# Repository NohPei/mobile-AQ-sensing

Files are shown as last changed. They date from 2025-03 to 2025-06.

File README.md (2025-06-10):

**NOTE:** *this repository and README file are still actively under development* 
---

*last updated: 6/9/2025*

# Mobile AQ Sensing Unit Overview

- **Raspberry Pi 4B** (Raspberry Pi OS Bookworm)
- **DS3231 RTC** (real-time clock module)
- **MQ Gas Sensors**:
  - MQ-3 (Alcohol)
  - MQ-4 (Methane)
  - MQ-8 (Hydrogen)
  - All read via **ADS1115 16-bit ADC**
- **Adafruit Breakout board Plantower PMSA003I** (Particulate Matter Sensor, PM1.0 / PM2.5 / PM10)
- **GY-BNO08X** (9 DoF IMU — accelerometer, gyro, magnetometer)
- **Adafruit SCD41** (True/NDIR CO₂, Temperature, Humidity)
- **Adafruit ENS160 MOX Gas Sensor** (TVOC, AQI, eCO₂)
- **DFRobot SEN0571** (Qualitative Odor Sensor)
- **GT-U7 GPS & GNSS Antenna Amplifier**

- [3D printed enclosure](https://github.com/NohPei/mobile-AQ-documentation/blob/main/v2-enclosure.stl)

**NOTE:** why both ENS160 and SCD41? We could use only SCD41 to measure *true* CO₂ (which isn't affected by VOCs like the ENS160), but we wanted something to measure TVOC/VOCs
- while ENS160 is currently included, we are actively searching to replace it with an alternative sensor for VOCs only

### TVOC vs. VOC
- VOCs (Volatile Organic Compounds) = individual or specific groups of volatile organic compounds.
- TVOC (Total Volatile Organic Compounds) = represents the total concentration of all volatile organic compounds in the air.

# How are the different sensors interfaced?
- I2C: RTC, MQs (x3), IMU, ENS160, SCD41, PM
- UART: GPS

# Sensors + Data Structure 
Overview and in-depth resources for the sensors, type of data they capture, and output format of the CSV.

Each row in the CSV file contains a timestamped sensor reading from the mobile air quality sensing unit. The columns are listed below:

| Column Name | Description | Units |
|---|---|---|
| `Timestamp (ms)` | System timestamp when data was logged | milliseconds |
| `GPS Timestamp(UTC)`| UTC timestamp from GPS module | ISO 8601 or seconds |
| `Latitude` | Latitude position from GPS | degrees |
| `Longitude` | Longitude position from GPS | degrees |
| `MQ-3 Voltage` | Raw analog voltage from MQ-3 sensor | volts |
| `MQ-4 Voltage` | Raw analog voltage from MQ-4 sensor | volts |
| `MQ-8 Voltage` | Raw analog voltage from MQ-8 sensor | volts |
| `MQ-3 R_s` | Sensor resistance for MQ-3 | ohms (Ω) |
| `MQ-4 R_s` | Sensor resistance for MQ-4 | ohms (Ω) |
| `MQ-8 R_s` | Sensor resistance for MQ-8 | ohms (Ω) |
| `SCD41 CO₂` | CO₂ concentration | ppm |
| `SCD41 Temperature` | Ambient temperature | °C |
| `SCD41 Humidity` | Relative humidity | % |
| `PM1.0` | Particulate matter 1.0 µm concentration | µg/m³ |
| `PM2.5` | Particulate matter 2.5 µm concentration | µg/m³ |
| `PM10` | Particulate matter 10 µm concentration | µg/m³ |
| `Accel X` | X-axis acceleration | m/s² |
| `Accel Y` | Y-axis acceleration | m/s² |
| `Accel Z` | Z-axis acceleration | m/s² |
| `Gyro X` | X-axis angular velocity | °/s |
| `Gyro Y` | Y-axis angular velocity | °/s |
| `Gyro Z` | Z-axis angular velocity | °/s |
| `Mag X` | X-axis magnetic field | µT |
| `Mag Y` | Y-axis magnetic field | µT |
| `Mag Z` | Z-axis magnetic field | µT |

### Real-Time Clock (ds3231) -> Timestamp (ms)
- ex) 2025-05-07 00:34:16.522

### GPS (GT-U7 + GNSS antenna amplifier) -> GPS Timestamp (UTC), Latitude,Longitude
- ex) 2025-05-07 04:34:16,42.29262116666666,-83.71489916666667

### Gas Sensors (MQ Series) -> Voltage
[resource 1](https://www.theengineeringprojects.com/2024/04/mq-gas-sensor-series.html)
[resource 2](https://robocraze.com/blogs/post/mq-series-gas-sensor)
[resource 3](https://iotbyhvm.ooo/mq-gas-sensors-gas-sensors/)

MQ-3 = H2, LPG, CH4, CO, Alcohol, Smoke or Propane
- [MQ-3 datasheet](https://cdn.sparkfun.com/assets/6/a/1/7/b/MQ-3.pdf)
MQ-4 = Methane, CNG
MQ-8 = Hydrogen Sulfide 
- outputs are voltages, representing raw output from sensor 
    - reflects concentration of gas it is sensing 

- ex) 0.3605,0.165,0.34450000000000003
**note**: tells us the concentration of a gas in part per million (ppm) according to the resistance ratio of the sensor (RS/R0). MQ senors have a built-in variable resistor that changes its value according to the concentration of gas. If the concentration is High, the resistance decreases,  if the concentration is low, the resistance increases

MQ-3 R_s,MQ-4 R_s,MQ-8 R_s
ex) 128696.25520110958,293030.303030303,135137.88098693758,

(ENS160 is optional...)
ENS160 TVOC,ENS160 eCO₂,ENS160 AQI
datasheet: https://cdn-learn.adafruit.com/assets/assets/000/115/331/original/SC_001224_DS_1_ENS160_Datasheet_Rev_0_95-2258311.pdf 
TVOC values: 0 - 65,000
eCO₂ values: 400 - 65,000 
AQI values: 1-5
- ex) 0,400,1

SCD41 CO₂,SCD41 Temperature,SCD41 Humidity,
ex) 590,24.380483710994127,29.660486762798506

DFROBOT SEN0571 Odor Sensor (*qualitative* sensor...)
[resource](https://docs.cirkitdesigner.com/component/8f45805b-c744-4d19-9426-4d6299082ad4/fermion-mems-odor-smell-gas-detection-sensor) <- although the wiring instructions are incorrect, that resource has good notes

PM1.0,PM2.5,PM10
ex) 1,1,3

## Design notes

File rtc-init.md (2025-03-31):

### DS3231 RTC Setup on Raspberry Pi OS (Bookworm)

To get the DS3231 RTC working reliably on Raspberry Pi OS (Bookworm), follow these steps:

1. enable i2c using `sudo raspi-config`, and verify the RTC is detected at address `0x68` using `i2cdetect -y 1`.
2. In `/boot/firmware/config.txt`, add the following line all the way at the bottomt to enable the overlay:

```ini
dtoverlay=i2c-rtc,ds3231
```
3. Add the RTC driver to `/etc/modules`: (underscore!)
```ini
rtc_ds1307
```
4. Add the driver to `/etc/initramfs-tools/modules`: (hyphen!)
```ini
rtc-ds1307
```
- then update initramfs tools:
```bash
sudo update-initramfs -u
```

5. Create fallback script at `/usr/local/bin/fallback_rtc_init.sh`:
```bash
#!/bin/bash

LOG_TAG="FALLBACK_RTC"
I2C_BUS=1
RTC_ADDRESS=0x68

logger -t "$LOG_TAG" "Starting RTC fallback init..."

# Load RTC driver
modprobe rtc_ds1307
logger -t "$LOG_TAG" "Loaded rtc_ds1307 driver."

# If /dev/rtc0 doesn't exist, try to register the device
if [ ! -e /dev/rtc0 ]; then
    logger -t "$LOG_TAG" "/dev/rtc0 not found. Attempting manual registration..."
    echo "ds3231 $RTC_ADDRESS" > /sys/class/i2c-adapter/i2c-${I2C_BUS}/new_device 2>/dev/null
    sleep 1
fi

# If RTC is now present
if [ -e /dev/rtc0 ]; then
    logger -t "$LOG_TAG" "RTC registered successfully at /dev/rtc0."
    sleep 1

    # Check system time before setting it from RTC
    CURRENT_YEAR=$(date +%Y)
    if [ "$CURRENT_YEAR" -lt 2022 ]; then
        if hwclock -s; then
            logger -t "$LOG_TAG" "System time set from RTC: $(hwclock -r)"
        else
            logger -t "$LOG_TAG" "ERROR: hwclock failed to read from RTC after registration."
        fi
    else
        logger -t "$LOG_TAG" "System time already appears valid. Skipping hwclock -s."
    fi
else
    logger -t "$LOG_TAG" "ERROR: /dev/rtc0 still not available. RTC registration failed or device not present."
fi
```
- make it executable: `sudo chmod +x /usr/local/bin/fallback_rtc_init.sh`

6. Make the systemd serivce (load module, manually register if missing, set system clock) at `/etc/systemd/system/fallback-rtc.service`:
```ini
[Unit]
Description=Manual Fallback RTC Init
After=multi-user.target
ConditionPathExists=/dev/i2c-1

[Service]
Type=oneshot
ExecStart=/usr/local/bin/fallback_rtc_init.sh
RemainAfterExit=yes

[Install]
WantedBy=multi-user.target
```
- reload & enable that:
```bash
sudo systemctl daemon-reload
sudo systemctl enable fallback-rtc.service
```

7. (optional/overkill but good for system longevity and consistency) sync RTC if NTP sync happens (pi connects to network) at `/usr/local/bin/rtc_writeback.sh`:
```bash
#!/bin/bash

LOG_TAG="RTC_WRITEBACK"

logger -t "$LOG_TAG" "Waiting for NTP synchronization..."

MAX_TRIES=60
for i in $(seq 1 $MAX_TRIES); do
    SYNCED=$(timedatectl show -p NTPSynchronized --value)
    if [ "$SYNCED" = "yes" ]; then
        logger -t "$LOG_TAG" "System clock synchronized, writing to RTC..."
        hwclock -w && logger -t "$LOG_TAG" "RTC updated from system time."
        exit 0
    fi
    sleep 2
done

logger -t "$LOG_TAG" "ERROR: NTP sync not achieved within timeout."
exit 1
```
- make it executable: `sudo chmod +x /usr/local/bin/rtc_writeback.sh`

8. Create the systemd service for it at `/etc/systemd/system/rtc-writeback.service`:
```ini
[Unit]
Description=Write system time to RTC after NTP sync
After=network-online.target systemd-timesyncd.service
Requires=systemd-timesyncd.service

[Service]
Type=oneshot
ExecStart=/usr/local/bin/rtc_writeback.sh
TimeoutStartSec=90

[Install]
WantedBy=multi-user.target
```
- reload & enable that:
```bash
sudo systemctl daemon-reload
sudo systemctl enable fallback-rtc.service
```

### Summary:   
1. this will make RTC work on every boot with/without connectivity and set the system time to correctly use the hardware clock. 
2. bonus: will resync with NTP when Wi-Fi connectivity happens so RTC is updated from system time.

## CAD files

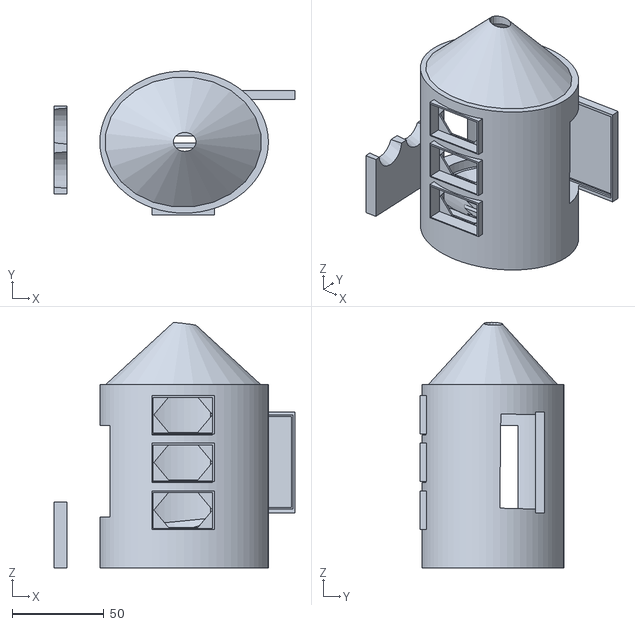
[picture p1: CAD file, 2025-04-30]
v2-enclosure.stl
131.5 x 78.5 x 134.0

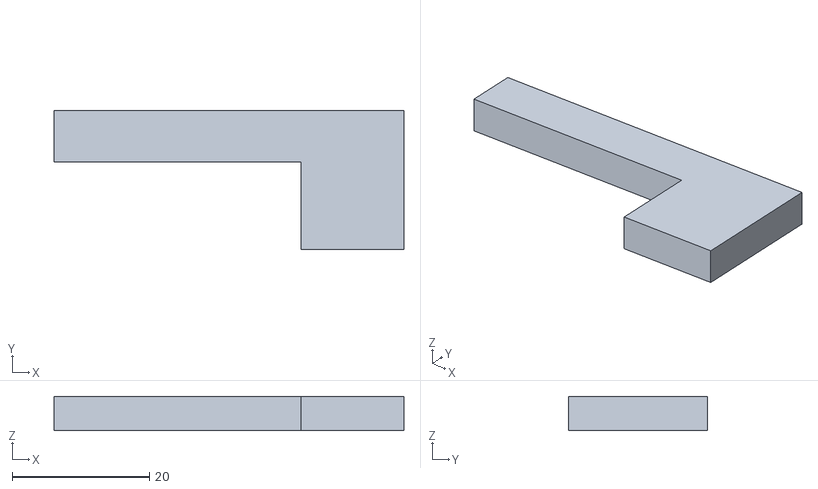
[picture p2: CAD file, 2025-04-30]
PM_sensor_plug.stl
51.0 x 20.2 x 5.00

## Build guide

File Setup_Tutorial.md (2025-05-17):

# Mobile Gas Sensing Module Setup Tutorial

## Table of Contents

1. [Introduction](#introduction)
2. [Hardware Requirements](#hardware-requirements)
3. [Assembly Instructions](#assembly-instructions)
4. [Software Setup](#software-setup)
   - [Operating System Installation](#operating-system-installation)
   - [Required Libraries](#required-libraries)
   - [Sensor Configuration](#sensor-configuration)
5. [RTC Configuration](#rtc-configuration)
   - [DS3231 Setup](#ds3231-setup)
   - [Time Synchronization](#time-synchronization)
6. [Data Collection](#data-collection)
7. [Troubleshooting](#troubleshooting)
8. [Maintenance](#maintenance)
9. [References](#references)

## Introduction

This guide provides step-by-step instructions for building and configuring a mobile gas sensing module from scratch. Follow each section in order for a complete setup.

## Software Requirement

#### Operating System Installation

Download it through https://www.raspberrypi.com/software/

In this repo, Raspberry Pi 5, 64 bit enhanced version is installed

#### Required Libraries (in python venv)
To make sure you can access the sysled as indication. You can run following command to create new rule and change the permission of sysled:

```
sudo nano /etc/udev/rules.d/99-led-permissions.rules
```

Type following command in the new rules:
```
SUBSYSTEM=="leds", KERNEL=="ACT", MODE="0666"
```

Reload rules:
```
sudo udevadm control --reload-rules
sudo udevadm trigger
```

If none of the above things work, manually modify the permission with 
```
sudo chmod 666 /sys/class/leds/ACT/brightness
```

1. ADS1115 => pip install adafruit-circuitpython-ads1x15
2. lgpio (not defaulty installed for pi5, higher performance) => pip install lgpio
3.

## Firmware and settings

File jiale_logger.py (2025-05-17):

import board # board pinout abstract
import busio # board bus abstract
import adafruit_ads1x15.ads1115 as ADS # Four channel ADC
from adafruit_ads1x15.analog_in import AnalogIn # Analog read function
import adafruit_scd4x # CO2 sensor

import os
import time
from datetime import datetime,timezone
import pytz
import csv
import argparse

import matplotlib.pyplot as plt
from matplotlib.animation import FuncAnimation
from collections import deque
import threading
import queue

import utils
from utils import config
print("utils imported")

class DataCollector(threading.Thread):
    def __init__(self, data_queue):
        super().__init__()
        self.data_queue = data_queue
        self.running = True
        self.daemon = True  # Thread will exit when main program exits

    def run(self):
        # Initialize sensors
        i2c = busio.I2C(board.SCL, board.SDA, frequency=config.I2C_FREQ) 
        ads = ADS.ADS1115(i2c, address=config.I2C_ADDRESS)
        scd41 = adafruit_scd4x.SCD4X(i2c)
        mq_sensors = {
            "MQ-3 (Alcohol)": AnalogIn(ads, ADS.P0),
            "MQ-4 (Methane)": AnalogIn(ads, ADS.P1),
            "MQ-8 (Hydrogen)": AnalogIn(ads, ADS.P3)
        }
        scd41.start_periodic_measurement()
        # Add the warm-up function call here
        print("Starting sensor warm-up...")
        utils.warm_up(5)  # Pass the number of seconds to warm up
        print("Warm-up complete, beginning data collection")
        csv_filename = f"sensor_log.csv"
        with open(csv_filename, mode='w', newline='') as file:
            writer = csv.writer(file)
            writer.writerow(config.SENSOR_HEADERS)
            print("Logging data to {}. Ctrl+C to stop.".format(csv_filename))
            
            while self.running:
                timestamp = datetime.now()
                mq_readings = [mq_sensor.voltage for mq_sensor in mq_sensors.values()]
                if scd41.data_ready:
                    scd41_readings = [scd41.CO2, scd41.temperature, scd41.relative_humidity]
                else:
                    scd41_readings = [-1, -1, -1]
                # Write to CSV
                writer.writerow([timestamp.strftime("%Y-%m-%d %H:%M:%S.%f")[:-3],
                                *mq_readings, 
                                *scd41_readings])
                file.flush()
                
                # Send data to plotting thread
                if self.data_queue is not None:
                    self.data_queue.put((timestamp, 
                                         *mq_readings, 
                                         *scd41_readings))
                time.sleep(0.1)  # Adjust sampling rate as needed

    def stop(self):
        self.running = False

def main():
    parser = argparse.ArgumentParser(description='Gas sensor data logger with optional plotting')
    parser.add_argument('--plot', action='store_true', help='Enable plotting')
    args = parser.parse_args()
    plot_enabled = args.plot
    # Set up the LED
    utils.set_led(0)

    if plot_enabled:
        # Create figure and axes
        fig, ax = plt.subplots(4, 1, figsize=(10, 8))
        max_points = 100
        
        # Create deques for data
        times = deque(maxlen=max_points)
        mq3_data = deque(maxlen=max_points)
        mq4_data = deque(maxlen=max_points)
        mq8_data = deque(maxlen=max_points)
        co2_data = deque(maxlen=max_points)

        # Initialize plots
        lines = []
        labels = ['MQ-3 (Alcohol)', 
                  'MQ-4 (Methane)', 
                  'MQ-8 (Hydrogen)',
                  'CO2 (ppm)']
        for i, axis in enumerate(ax):
            line, = axis.plot([], [], 'r-', label=labels[i])
            lines.append(line)
            if i == 3:
                axis.set_ylabel('CO2 (ppm)')
                axis.set_ylim(400, 5000)
            else:
                axis.set_ylabel('Voltage (V)')
            axis.set_xlabel('Time (s)')
            axis.grid(True)
            axis.legend()


        start_time = None
        data_queue = queue.Queue()
    else:
        data_queue = None
        print("Plotting disabled")
    
    # Create and start data collector thread
    collector = DataCollector(data_queue)
    collector.start()

    if plot_enabled:
        def update_plot(frame):
            nonlocal start_time
            
            # Get all available data from queue
            while not data_queue.empty():
                timestamp, mq3, mq4, mq8, co2, temp, hum = data_queue.get()
                if start_time is None:
                    start_time = timestamp

                elapsed = (timestamp - start_time).total_seconds()

                times.append(elapsed)
                mq3_data.append(mq3)
                mq4_data.append(mq4)
                mq8_data.append(mq8)
                if co2 is not None:
                    co2_data.append(co2)
                elif len(co2_data) > 0:
                    co2_data.append(co2_data[-1])
                else:
                    co2_data.append(0)

            # Update each line
            data_sets = [mq3_data, mq4_data, mq8_data, co2_data]
            for i, (line, data) in enumerate(zip(lines, data_sets)):
                line.set_data(list(times), list(data))
                axis = line.axes
                axis.relim()
                axis.autoscale_view()

            return lines

        # Start animation in main thread
        ani = FuncAnimation(fig, update_plot, interval=10, blit=True, save_count=max_points)

        try:
            plt.show()
        except KeyboardInterrupt:
            pass
    else:
        try:
            print("Press Ctrl+C to stop")
            while True:
                time.sleep(1)
        except KeyboardInterrupt:
            pass
    collector.stop()
    collector.join()
    if plot_enabled:
        plt.close()
    print("Logger stopped")

if __name__ == "__main__":
    main()

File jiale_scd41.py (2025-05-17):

import time
import board
import adafruit_scd4x
from utils import config
import busio

i2c = busio.I2C(board.SCL, board.SDA, frequency=config.I2C_FREQ) 
scd4x = adafruit_scd4x.SCD4X(i2c)
scd4x.reinit()

print("Starting measurements...")
scd4x.start_periodic_measurement()
initial_time = time.time()
while True:
    if scd4x.data_ready:
        scd4x_readings = [scd4x.CO2, scd4x.temperature, scd4x.relative_humidity]
        print("Elapsed time since last measurement: ", time.time() - initial_time)
        print(f"CO2: {scd4x_readings[0]}ppm, Temperature: {scd4x_readings[1]}C, Humidity: {scd4x_readings[2]}%")
        initial_time = time.time()
        time.sleep(5)

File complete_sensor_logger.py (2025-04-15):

import time
import board
import busio
import serial
import csv
import threading
import glob
from datetime import datetime
import pynmea2
import adafruit_scd4x
import adafruit_ens160
import adafruit_ads1x15.ads1115 as ADS
from adafruit_ads1x15.analog_in import AnalogIn
import adafruit_bno08x
from adafruit_bno08x.i2c import BNO08X_I2C
from adafruit_ens160 import NORMAL_OP, START_UP, WARM_UP, INVALID_OUT, MODE_STANDARD
from adafruit_pm25.i2c import PM25_I2C

# using ACT led to verify we have started logging data
led_path="/sys/class/leds/ACT/brightness"

def set_led(state):
  with open(led_path, "w") as led:
    led.write("1" if state else "0")
set_led(0)

# Initialize I2C - added frequency for PM sensor...
reset_pin = None
i2c = busio.I2C(board.SCL, board.SDA, frequency=100000)

# Initialize ADS1115 (MQ Gas Sensors)
ads = ADS.ADS1115(i2c)
mq_sensors = {
    "MQ-3 (Alcohol)": AnalogIn(ads, ADS.P0),
    "MQ-4 (Methane)": AnalogIn(ads, ADS.P1),
    "MQ-8 (Hydrogen)": AnalogIn(ads, ADS.P3)
}

# Initialize IMU (GY-BNO08X)
imu = BNO08X_I2C(i2c, address=0x4B)
imu.enable_feature(adafruit_bno08x.BNO_REPORT_ACCELEROMETER)
imu.enable_feature(adafruit_bno08x.BNO_REPORT_GYROSCOPE)
imu.enable_feature(adafruit_bno08x.BNO_REPORT_MAGNETOMETER)

# Initialize Serial Interfaces
gps_uart = serial.Serial("/dev/ttyAMA0", baudrate=9600, timeout=0.1)

# Initialize Sensors
ens160 = adafruit_ens160.ENS160(i2c)
ens160.mode = MODE_STANDARD
scd41 = adafruit_scd4x.SCD4X(i2c)
scd41.start_periodic_measurement()
pm25 = PM25_I2C(i2c, reset_pin)

print("ENS160 firmware:", ens160.firmware_version)
print("ENS160 mode:", ens160.mode)

# Store latest GPS coordinates and time
gps_lock = threading.Lock()
latest_lat, latest_lon, latest_gps_time = None, None, None
last_gps_fix_timestamp = None

# **Threaded GPS Reading**
def read_gps_continuous():
    global latest_lat, latest_lon, latest_gps_time, last_gps_fix_timestamp
    while True:
        try:
            line = gps_uart.readline().decode('utf-8', errors='ignore').strip()
            if line.startswith("$GPRMC"):
                msg = pynmea2.parse(line)
                if msg.status == 'A':
                    gps_datetime = datetime.combine(msg.datestamp, msg.timestamp)
                    with gps_lock:
                        latest_gps_time = gps_datetime
                        last_gps_fix_timestamp = time.time()
            elif line.startswith("$GPGGA"):
                msg = pynmea2.parse(line)
                if hasattr(msg, 'gps_qual') and msg.gps_qual > 0:
                    with gps_lock:
                        latest_lat, latest_lon = msg.latitude, msg.longitude
                        last_gps_fix_timestamp = time.time()
        except Exception as e:
            print(f"GPS Error: {e}")
        time.sleep(0.05)

# Start GPS Thread
gps_thread = threading.Thread(target=read_gps_continuous, daemon=True)
gps_thread.start()

# **Warm-Up Period (1 Minute)**
warmup_time = 1 * 60
print(f"Starting warm-up period ({warmup_time // 60} minutes)...")
start_time = time.time()
while time.time() - start_time < warmup_time:
    remaining_time = warmup_time - (time.time() - start_time)
    print(f"Warm-up time remaining: {int(remaining_time // 60)}m {int(remaining_time % 60)}s", end="\r")
    set_led(1)
    time.sleep(1)
    set_led(0)
    time.sleep(1)
print("\nWarm-up complete. Starting data collection...")

set_led(1)

# **Create and Open CSV File for Logging**
first_timestamp = datetime.now().strftime("%Y-%m-%d_%H-%M-%S")
csv_filename = f"sensor_log_{first_timestamp}.csv"

with open(csv_filename, mode='w', newline='') as file:
    writer = csv.writer(file)
    writer.writerow([
       "Timestamp (ms)", "GPS Timestamp (UTC)", "Latitude", "Longitude",
    	"MQ-3 Voltage", "MQ-4 Voltage", "MQ-8 Voltage",
        "MQ-3 R_s", "MQ-4 R_s", "MQ-8 R_s",
        "ENS160 TVOC", "ENS160 eCO₂", "ENS160 AQI",
        "SCD41 CO₂", "SCD41 Temperature", "SCD41 Humidity",
        "PM1.0", "PM2.5", "PM10",
        "Accel X", "Accel Y", "Accel Z",
        "Gyro X", "Gyro Y", "Gyro Z",
        "Mag X", "Mag Y", "Mag Z"
    ])

    def calculate_resistance(v_out, v_circuit=5.0, r_load=10000):
        if v_out == 0:
            return None
        return ((v_circuit - v_out) / v_out) * r_load

    try:
        print(f"Logging sensor data to {csv_filename}... Press CTRL+C to stop.")

        while True:
            timestamp = datetime.now().strftime("%Y-%m-%d %H:%M:%S.%f")[:-3]
            with gps_lock:
                lat, lon = latest_lat, latest_lon
                gps_time = latest_gps_time.strftime("%Y-%m-%d %H:%M:%S") if latest_gps_time else None
                gps_age = time.time() - last_gps_fix_timestamp if last_gps_fix_timestamp else None

            if gps_age and gps_age > 2:
                print(f"GPS fix is stale ({gps_age:.1f} seconds old)")

            mq_values = [channel.voltage for channel in mq_sensors.values()]
            mq_resistances = [calculate_resistance(v) for v in mq_values]

            scd41_co2, scd41_temp, scd41_hum = None, None, None
            try:
                scd41_co2 = scd41.CO2
                scd41_temp = scd41.temperature
                scd41_hum = scd41.relative_humidity
            except OSError:
                print("SCD41 error detected. Restarting sensor...")
                scd41.stop_periodic_measurement()
                time.sleep(2)
                scd41.start_periodic_measurement()

            try:
                if scd41_temp is not None and scd41_hum is not None:
                    ens160.temperature_compensation = scd41_temp
                    ens160.humidity_compensation = scd41_hum
            except Exception as e:
                print(f"ENS160 compensation error: {e}")

            if ens160.new_data_available:
                validity = ens160.data_validity
                if validity == NORMAL_OP:
                    try:
                        data = ens160.read_all_sensors()
                        ens160_tvoc = data["TVOC"]
                        ens160_eco2 = data["eCO2"]
                        ens160_aqi = data["AQI"]
                    except Exception as e:
                        print(f"ENS160 read error: {e}")
                        ens160_tvoc, ens160_eco2, ens160_aqi = None, None, None
                else:
                    print(f"ENS160 not ready → status: {validity}")
                    ens160_tvoc, ens160_eco2, ens160_aqi = None, None, None
            else:
                ens160_tvoc, ens160_eco2, ens160_aqi = None, None, None

            try:
                aqdata = pm25.read()
                pm1_0 = aqdata["pm10 env"]
                pm2_5 = aqdata["pm25 env"]
                pm10 = aqdata["pm100 env"]


            except RuntimeError:
                print("Unable to read from sensor, retrying...")
                continue
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

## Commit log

2025-03-18 uploaded complete sensor logging code
2025-04-01 added to sensors/data structure
2025-04-15 updated code for new pm sensor
2025-04-15 new pm sensor update
2025-04-30 added 3d printed enclosure STLs
    [Copy of v2-enclosure.stl, New AQ sensor plug (1).stl]
2025-04-30 Rename New AQ sensor plug (1).stl to PM_sensor_plug.stl
    [PM_sensor_plug.stl]
2025-04-30 Rename Copy of v2-enclosure.stl to v2-enclosure.stl
    [v2-enclosure.stl]
2025-04-30 added 3D enclosure details
2025-05-13 add jiale_logger.py
    [sensor_log.csv]
2025-05-17 update plotting function as a argument, which can be turned on/off
    [sensor_log.csv]
2025-05-17 add scd41 plotting, not fully working now
    [sensor_log.csv]
2025-06-09 updated sensor data & format
2025-06-10 updated sensor list
